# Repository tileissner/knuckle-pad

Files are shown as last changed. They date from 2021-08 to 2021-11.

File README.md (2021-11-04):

# knuckle-pad

After getting into custom keyboards I was looking to get a gaming keypad to free up mouse space for shooters. Since none of the possible options were 100% what I wanted, were too expensive or simply not available anymore I decided to design my very own keyboard from scratch.

# Rev. 1

In Rev. 1 the Knuckle Pad features a 4x6+5 keys in a ortholinear layout, offering 3 1.25u pinky keys, 4 radially positioned thumb keys and a uniquely positioned key to press with the head of your metacarpal bone (what I call "inner knuckle"). However, after actually using the first prototype the placement of said "knuckle key" turned out to be way to aggresive (too low, felt like it was in the way).

[//]: # (add picture of layout here)

# Rev. 2

Rev. 2 features a top-mounted MCU to reduce the overall build height, but sacrifices the keys "5" and "T" for it. Furthermore, I added a slight WASD columnar stagger for better ergonomics and moved the "knuckle key" up to right under the 4th row of the 1st column. 

The 1.25u keys in the 1st col have also been replaced with 1u keys for better keycap profile compatibility. They have been moved to the edge of the PCB to still have these keys separated from the rest and emulate the feeling of a "normal" keyboard.

Rev. 2 also features VIAL support so you can map the keys to your personal preference very easily.

[//]: # (add picture of layout here)

# Pictures

# Q&A:

Q: Why the knuckle key?

A: At some point in time I (unconsciously) developed the habit of using my knuckles to press CTRL when playing shooters as I pressing said key with my pinky fingers felt rather uncomfortable.

[//]: # (Q: How am I gonna flame my team mates with half a keyboard?)

[//]: # (Why the hell do you still use the in-game text chat?)

# Ordering PCBs

# Parts needed

# Future plans

- <del>switch plate</del>
- <del>Bottom plate</del>
- <del>Change to black pill microcontroller</del> (No purpose in doing this anymore as pro micros with usb-c are sufficient for this kb)
- Hot-Swap
- Might design a stacked acrylic case if I'm feeling spicy (not anytime soon though)
- Since I designed this KB after finding out about the free montly prototype that allpcb offered and since I wanted to use that service I was constrained to a maximum PCB area of 15000mm^2. Consequently, I could not have BOTH a top-mounted MCU AND all rows with 6 columns. Allpcb apparently discountinued that service (atleast if you haven't bought any PCBs in the last 6 months from them), so this means that if I'm doing a Rev. 3 I will not be constrained anymore by the max size for free prototypes and can have ALL the keys + a top-mounted MCU.

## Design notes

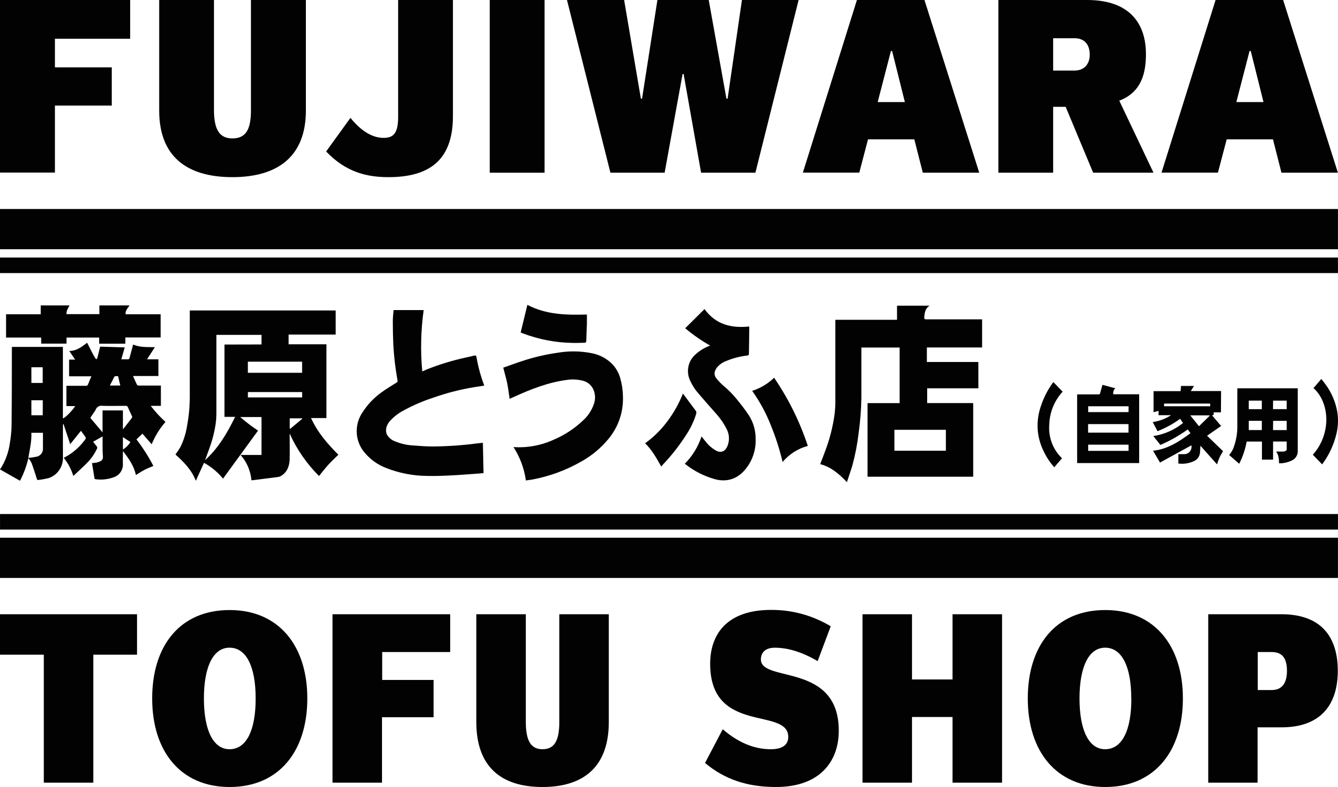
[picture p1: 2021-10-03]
v2/knuckle-pad-swPlate/815-8150931_fujiwara-tofu-shop-decal-fujiwara-tofu-shop-symbol.png

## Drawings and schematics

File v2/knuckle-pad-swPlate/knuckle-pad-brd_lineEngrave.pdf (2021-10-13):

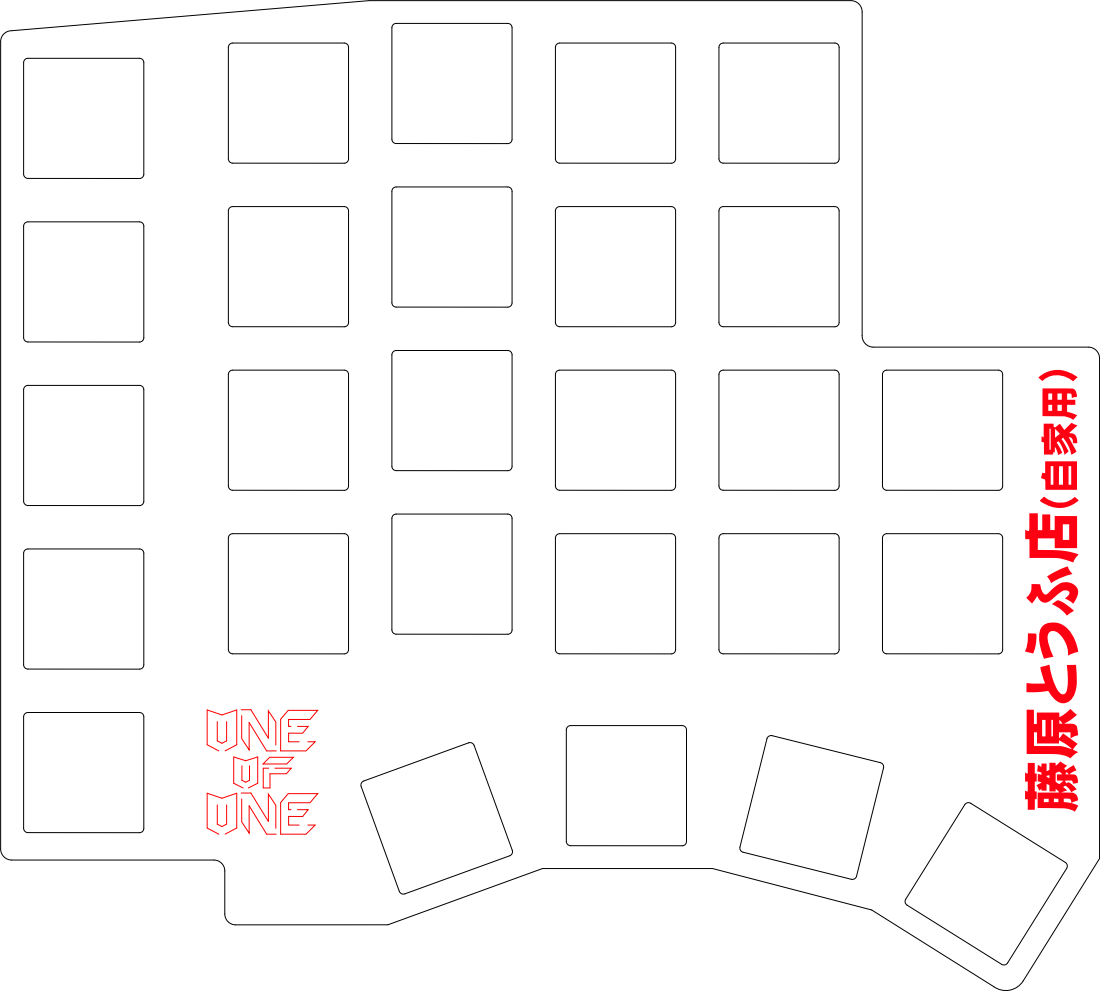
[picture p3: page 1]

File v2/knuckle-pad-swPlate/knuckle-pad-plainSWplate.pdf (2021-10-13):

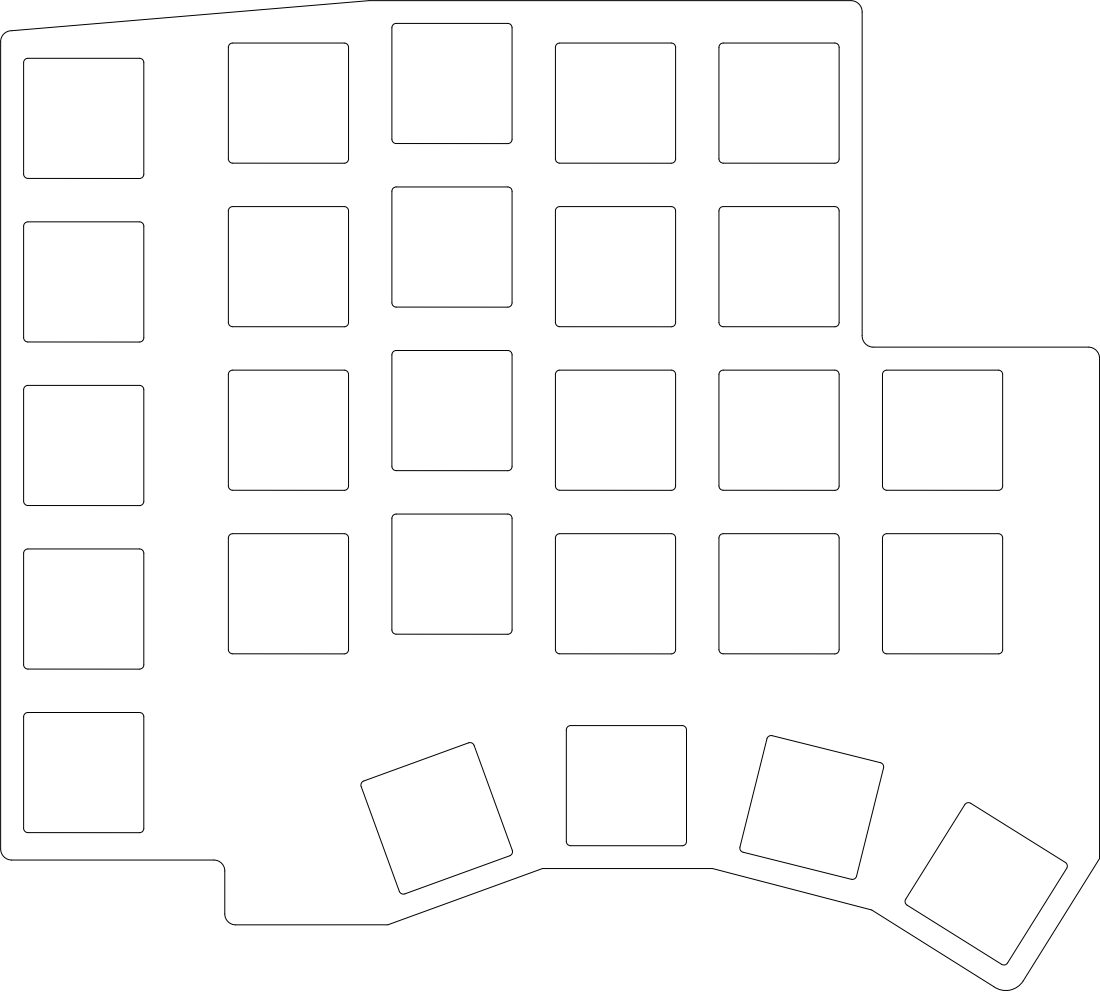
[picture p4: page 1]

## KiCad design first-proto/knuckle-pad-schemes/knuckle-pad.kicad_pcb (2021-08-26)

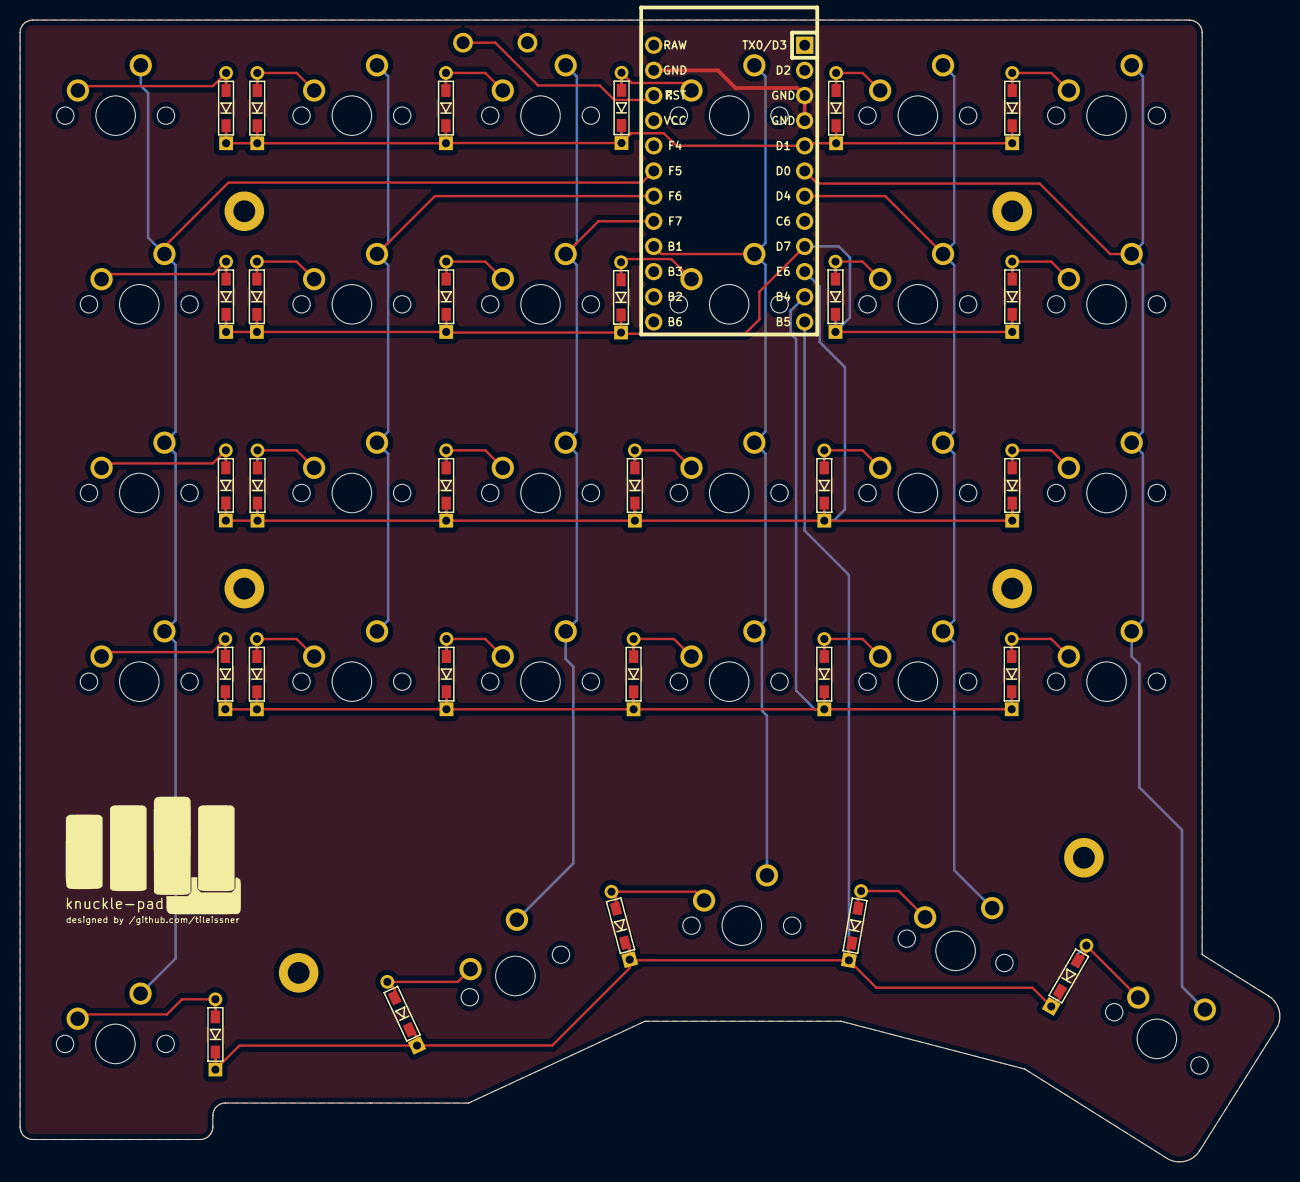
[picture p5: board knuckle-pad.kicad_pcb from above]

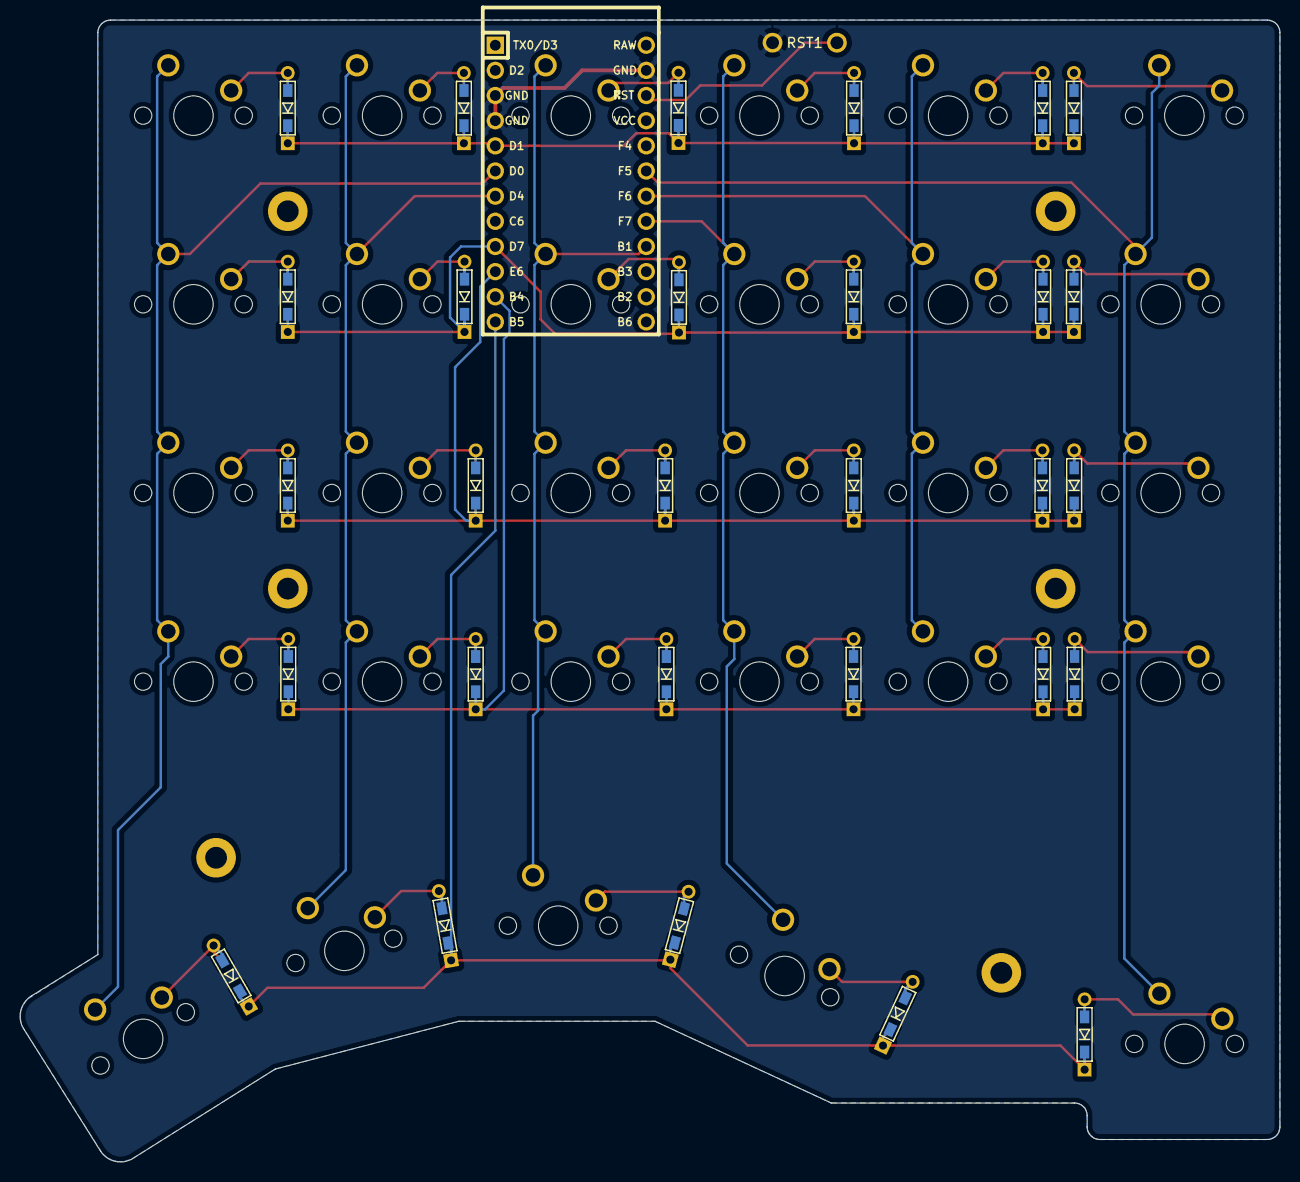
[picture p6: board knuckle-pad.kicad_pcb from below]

Board: 2 copper layers, 127.2 x 115.3 mm, 66 parts (31 on the bottom side), 42 nets.

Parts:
D1, D2, D3, D4, D5, D6, D7, D8, D9, D10, D11, D12, D13, D14, D15, D16, D17, D18, D19, D20, D21, D22, D23, D24, D25, D26, D27, D28, D29: D_Small; diode_TH_SMD
H1, H2, H3, H4, H5, H6: MountingHole; M2_HOLE_PCB
RST1: SW_Push; Switch_Reset_THT
SW1, SW5, SW6, SW7, SW8, SW9, SW10, SW11, SW12, SW13, SW14, SW15, SW16, SW17, SW18, SW19, SW20, SW21, SW22, SW23, SW24, SW25, SW26, SW27, SW28, SW29: SW_Push; MXOnly-1U-NoLED
SW2, SW3, SW4: SW_Push; MXOnly-1.25U-NoLED
U1: ProMicro; ArduinoProMicro

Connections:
GND: RST1.2, U1.3, U1.4, U1.23
unnamed: D1.2, SW1.1
unnamed: D2.2, SW2.1
unnamed: D3.2, SW3.1
unnamed: D4.2, SW4.1
unnamed: D5.2, SW5.1
unnamed: D6.2, SW6.1
unnamed: D7.2, SW7.1
unnamed: D8.2, SW8.1
unnamed: D9.2, SW9.1
unnamed: D10.2, SW10.1
unnamed: D11.2, SW11.1
unnamed: D12.2, SW12.1
unnamed: D13.2, SW13.1
unnamed: D14.2, SW14.1
unnamed: D15.2, SW15.1
unnamed: D16.2, SW16.1
unnamed: D17.2, SW17.1
unnamed: D18.2, SW18.1
unnamed: D19.2, SW19.1
unnamed: D20.2, SW20.1
unnamed: D21.2, SW21.1
unnamed: D22.2, SW22.1
unnamed: D23.2, SW23.1
unnamed: D24.2, SW24.1
unnamed: D25.2, SW25.1
unnamed: D26.2, SW26.1
unnamed: D27.2, SW27.1
unnamed: D28.2, SW28.1
unnamed: D29.2, SW29.1
RST: RST1.1, U1.22
col0: SW1.2, SW2.2, SW3.2, SW4.2, SW5.2, U1.19
col1: SW6.2, SW7.2, SW8.2, SW9.2, U1.18
col2: SW10.2, SW11.2, SW12.2, SW13.2, SW14.2, U1.17
col3: SW15.2, SW16.2, SW17.2, SW18.2, SW19.2, U1.16
col4: SW20.2, SW21.2, SW22.2, SW23.2, SW24.2, U1.7
col5: SW25.2, SW26.2, SW27.2, SW28.2, SW29.2, U1.6
row0: D1.1, D6.1, D10.1, D15.1, D20.1, D25.1, U1.5
row1: D2.1, D7.1, D11.1, D16.1, D21.1, D26.1, U1.9
row2: D3.1, D8.1, D12.1, D17.1, D22.1, D27.1, U1.10
row3: D4.1, D9.1, D13.1, D18.1, D23.1, D28.1, U1.11
row4: D5.1, D14.1, D19.1, D24.1, D29.1, U1.12

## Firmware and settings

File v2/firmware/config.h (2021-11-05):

#pragma once

#include "config_common.h"

/* USB Device descriptor parameter */
#define VENDOR_ID       0x746C
#define PRODUCT_ID      0x0001
#define DEVICE_VER      0x0002
#define MANUFACTURER    tileissner
#define PRODUCT         knuckle-pad
#define DESCRIPTION     knuckle-pad

/* key matrix size */
#define MATRIX_ROWS 5
#define MATRIX_COLS 6

/* key matrix pins */
#define MATRIX_ROW_PINS { C6, D7, E6, B4, B5 }
#define MATRIX_COL_PINS { F6, F7, B1, B3, B2, B6 }
#define UNUSED_PINS

/* COL2ROW or ROW2COL */
#define DIODE_DIRECTION COL2ROW

/* Set 0 if debouncing isn't needed */
#define DEBOUNCING_DELAY 5

/* Mechanical locking support. Use KC_LCAP, KC_LNUM or KC_LSCR instead in keymap */
#define LOCKING_SUPPORT_ENABLE

/* Locking resynchronize hack */
#define LOCKING_RESYNC_ENABLE

/* disable these deprecated features by default */
#define NO_ACTION_MACRO
#define NO_ACTION_FUNCTION

/* Bootmagic Lite key configuration */
#define BOOTMAGIC_LITE_ROW 0
#define BOOTMAGIC_LITE_COLUMN 1

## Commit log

2021-08-20 1st iteration of schemes
    [knuckle-pad.kicad_pcb, knuckle-pad.sch]
2021-08-20 updated pcb shape to (preliminary) final+added pwr_flag to schematic
    [knuckle-pad.kicad_pcb, knuckle-pad.sch]
2021-08-21 push before routing
    [knuckle-pad.kicad_pcb, knuckle-pad.sch]
2021-08-21 rounded all edges(
    [knuckle-pad.kicad_pcb]
2021-08-21 added 1st routing, needs optimization
    [knuckle-pad.kicad_pcb]
2021-08-22 finished routing
    [knuckle-pad.kicad_pcb]
2021-08-22 added logo and finalized routing
    [knuckle-pad-B_Cu.gbl, knuckle-pad-B_Mask.gbs, knuckle-pad-B_SilkS.gbo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]
2021-08-22 fixed no connect flags
    [knuckle-pad.sch]
2021-08-23 added ground on copper layers
    [knuckle-pad.kicad_pcb]
2021-08-23 changed switch footprint to mx-NoLed ones
    [knuckle-pad.kicad_pcb, knuckle-pad.sch]
2021-08-24 changed mounting hole pos to match plate
    [knuckle-pad-B_Cu.gbl, knuckle-pad-B_Mask.gbs, knuckle-pad-B_SilkS.gbo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]
2021-08-24 clean up
    [knuckle-pad-B_Cu.gbl, knuckle-pad-B_Mask.gbs, knuckle-pad-B_SilkS.gbo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]
2021-08-24 add gerbers.zip
2021-08-26 ordered first proto from allpcb
    [knuckle-pad-B_Cu.gbl, knuckle-pad-B_Mask.gbs, knuckle-pad-B_SilkS.gbo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]
2021-08-28 add switch plate
    [knuckle-pad.sch]
2021-09-17 v2 started -complete reroute; flipped ProMicro, changed diode footprint
    [knuckle-pad.kicad_pcb, knuckle-pad.sch]
2021-09-19 before changing holes
    [knuckle-pad.kicad_pcb]
2021-09-27 complete rework
    [knuckle-pad.kicad_pcb, knuckle-pad.kicad_sch]
2021-09-28 prelim version before trying to fit mcu cover and sw plate
    [knuckle-pad-B_Cu.gbl, knuckle-pad-B_Mask.gbs, knuckle-pad-B_Silkscreen.gbo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]
2021-09-29 moved mcu and switched back to traymount
    [knuckle-pad.kicad_pcb, knuckle-pad.kicad_sch]
2021-09-29 final v2, moved rst to outer edge
    [knuckle-pad-B_Cu.gbl, knuckle-pad-B_Mask.gbs, knuckle-pad-B_Silkscreen.gbo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]
2021-09-30 sw plate and mcu cover files
    [knuckle-pad.kicad_pcb, knuckle-pad.kicad_sch, knuckle-pad.sch]
2021-10-01 finalized MCU cover
    [knuckle-pad.kicad_pcb, knuckle-pad.kicad_sch, knuckle-pad.sch]
2021-10-03 finalized sw plate and mcu cover design
    [knuckle-pad.kicad_pcb, knuckle-pad.kicad_sch, knuckle-pad.sch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]
2021-10-04 added via firmware and moved all files to v2 dir
    [knuckle-pad.kicad_pcb, knuckle-pad.kicad_sch, knuckle-pad.sch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]
2021-10-05 fixed psycho engraving
    [knuckle-pad-Edge_Cuts.gm1, knuckle-pad-NPTH.drl, knuckle-pad-PTH.drl]
2021-11-04 add case files
    [knuckle-pad.kicad_pcb, knuckle-pad.kicad_sch, knuckle-pad.sch]
2022-12-29 add firmware
    [rad-pad-B_Cu.gbl, rad-pad-B_Mask.gbs, rad-pad-B_Silkscreen.gbo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]
